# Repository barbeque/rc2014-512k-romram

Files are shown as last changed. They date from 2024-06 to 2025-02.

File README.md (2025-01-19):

## The Board
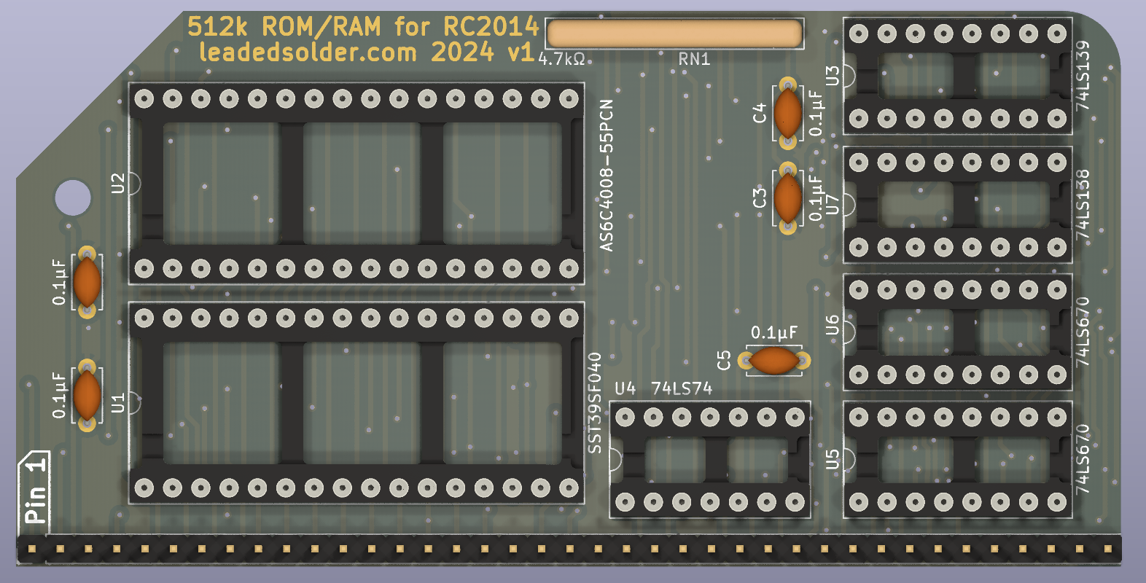
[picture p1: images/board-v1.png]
The board of version 1


## Licensing and Credits
This board is based on [the schematic listed on the RC2014 website](https://rc2014.co.uk/modules/512k-rom-512k-ram-module/), which is in turn derived from [Sergey Kiselev's Zeta 2 SBC](https://github.com/skiselev/zeta_sbc) (GPLv3). Please honour the licensing for any derivatives made of this board.

Symbol for the AS6C4008 ROM comes from SnapEDA.

## Version 2
Fixed:
 - D0 was not written into the 7474
 - A18 was not connected on the RAM, due to a buggy (copy-paste error) SnapEDA symbol.

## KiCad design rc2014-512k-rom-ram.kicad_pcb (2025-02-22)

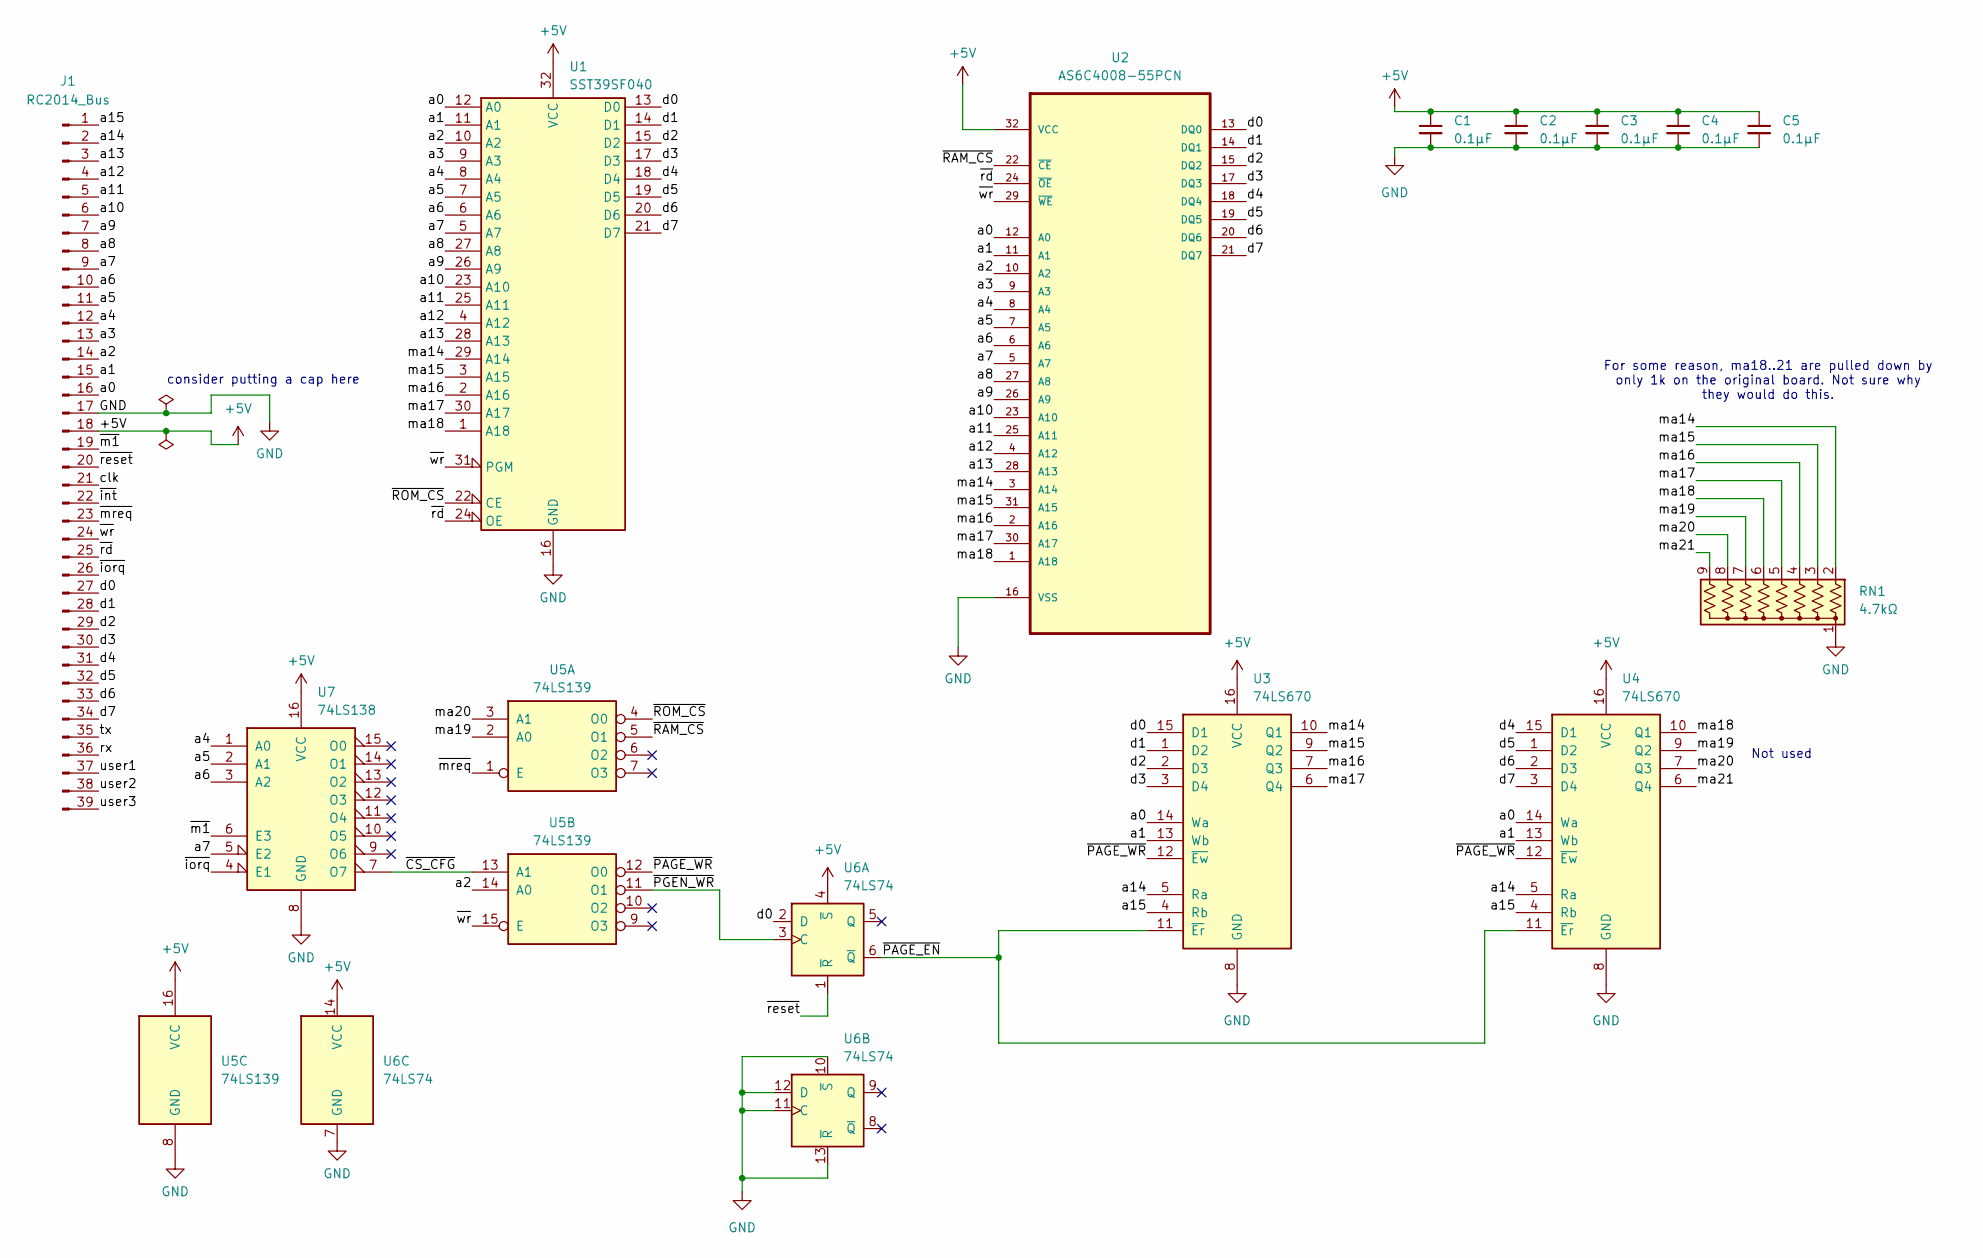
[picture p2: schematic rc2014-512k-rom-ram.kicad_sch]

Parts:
C1, C2, C3, C4, C5: 0.1µF; C_Disc_D4.7mm_W2.5mm_P5.00mm
J1: RC2014_Bus; PinHeader_1x39_P2.54mm_Vertical
RN1: 4.7kΩ; R_Array_SIP9
U1: SST39SF040; DIP-32_W15.24mm_Socket_LongPads
U2: AS6C4008-55PCN; DIP254P1524X393-32; MPN AS6C4008-55PCN
U3, U4: 74LS670; DIP-16_W7.62mm_Socket_LongPads
U5: 74LS139; DIP-16_W7.62mm_Socket_LongPads
U6: 74LS74; DIP-14_W7.62mm_Socket_LongPads
U7: 74LS138; DIP-16_W7.62mm_Socket_LongPads

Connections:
+5V: C1.1, C2.1, C3.1, C4.1, C5.1, J1.18, U1.32 (VCC), U2.32 (VCC), U3.16 (VCC), U4.16 (VCC), U5.16 (VCC), U6.4 (~S), U6.14 (VCC), U7.16 (VCC)
/a0: J1.16, U1.12 (A0), U2.12 (A0), U3.14 (Wa), U4.14 (Wa)
/a1: J1.15, U1.11 (A1), U2.11 (A1), U3.13 (Wb), U4.13 (Wb)
/a2: J1.14, U1.10 (A2), U2.10 (A2), U5.14 (A0)
/a3: J1.13, U1.9 (A3), U2.9 (A3)
/a4: J1.12, U1.8 (A4), U2.8 (A4), U7.1 (A0)
/a5: J1.11, U1.7 (A5), U2.7 (A5), U7.2 (A1)
/a6: J1.10, U1.6 (A6), U2.6 (A6), U7.3 (A2)
/a7: J1.9, U1.5 (A7), U2.5 (A7), U7.5 (E2)
/a8: J1.8, U1.27 (A8), U2.27 (A8)
/a9: J1.7, U1.26 (A9), U2.26 (A9)
/a10: J1.6, U1.23 (A10), U2.23 (A10)
/a11: J1.5, U1.25 (A11), U2.25 (A11)
/a12: J1.4, U1.4 (A12), U2.4 (A12)
/a13: J1.3, U1.28 (A13), U2.28 (A13)
/a14: J1.2, U3.5 (Ra), U4.5 (Ra)
/a15: J1.1, U3.4 (Rb), U4.4 (Rb)
/clk: J1.21
/d0: J1.27, U1.13 (D0), U2.13 (DQ0), U3.15 (D1), U6.2 (D)
/d1: J1.28, U1.14 (D1), U2.14 (DQ1), U3.1 (D2)
/d2: J1.29, U1.15 (D2), U2.15 (DQ2), U3.2 (D3)
/d3: J1.30, U1.17 (D3), U2.17 (DQ3), U3.3 (D4)
/d4: J1.31, U1.18 (D4), U2.18 (DQ4), U4.15 (D1)
/d5: J1.32, U1.19 (D5), U2.19 (DQ5), U4.1 (D2)
/d6: J1.33, U1.20 (D6), U2.20 (DQ6), U4.2 (D3)
/d7: J1.34, U1.21 (D7), U2.21 (DQ7), U4.3 (D4)
/ma14: RN1.2 (R1), U1.29 (A14), U2.3 (A14), U3.10 (Q1)
/ma15: RN1.3 (R2), U1.3 (A15), U2.31 (A15), U3.9 (Q2)
/ma16: RN1.4 (R3), U1.2 (A16), U2.2 (A16), U3.7 (Q3)
/ma17: RN1.5 (R4), U1.30 (A17), U2.30 (A17), U3.6 (Q4)
/ma18: RN1.6 (R5), U1.1 (A18), U2.1 (A18), U4.10 (Q1)
/ma19: RN1.7 (R6), U4.9 (Q2), U5.2 (A0)
/ma20: RN1.8 (R7), U4.7 (Q3), U5.3 (A1)
/ma21: RN1.9 (R8), U4.6 (Q4)
/rx: J1.36
/tx: J1.35
/user1: J1.37
/user2: J1.38
/user3: J1.39
/~CS_CFG: U5.13 (A1), U7.7 (O7)
/~PAGE_EN: U3.11 (~Er), U4.11 (~Er), U6.6 (~Q)
/~PAGE_WR: U3.12 (~Ew), U4.12 (~Ew), U5.12 (O0)
/~PGEN_WR: U5.11 (O1), U6.3 (C)
/~RAM_CS: U2.22 (CE), U5.5 (O1)
/~ROM_CS: U1.22 (CE), U5.4 (O0)
/~int: J1.22
/~iorq: J1.26, U7.4 (E1)
/~m1: J1.19, U7.6 (E3)
/~mreq: J1.23, U5.1 (E)
/~rd: J1.25, U1.24 (OE), U2.24 (OE)
/~reset: J1.20, U6.1 (~R)
/~wr: J1.24, U1.31 (PGM), U2.29 (WE), U5.15 (E)
GND: C1.2, C2.2, C3.2, C4.2, C5.2, J1.17, RN1.1 (common), U1.16 (GND), U2.16 (VSS), U3.8 (GND), U4.8 (GND), U5.8 (GND), U6.7 (GND), U6.10 (~S), U6.11 (C), U6.12 (D), U6.13 (~R), U7.8 (GND)

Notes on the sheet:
Not used
For some reason, ma18..21 are pulled down by only 1k on the original board. Not sure why they would do this.
consider putting a cap here

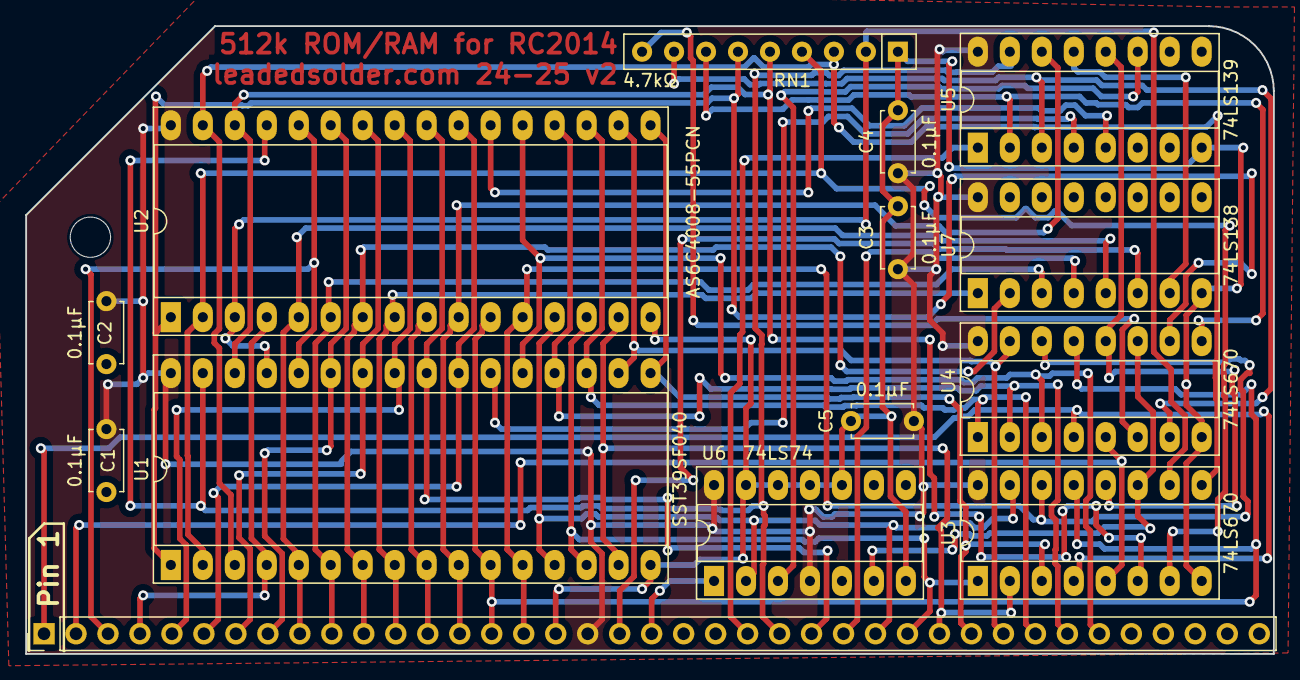
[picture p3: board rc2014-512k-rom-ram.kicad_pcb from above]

Board: 2 copper layers, 99.1 x 49.9 mm, 14 parts (0 on the bottom side), 46 nets.

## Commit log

2024-06-25 Redrawn schematic
    [rc2014-512k-rom-ram.kicad_pcb, rc2014-512k-rom-ram.kicad_sch]
2024-06-25 Finally fully routed
    [rc2014-512k-rom-ram.kicad_pcb, rc2014-512k-rom-ram.kicad_sch]
2024-06-25 Send v1 to fab
    [rc2014-512k-rom-ram.kicad_pcb]
2024-06-25 Send to JLCPCB
    [rc2014-512k-rom-ram.kicad_pcb]
2024-06-25 OSHW logo
    [rc2014-512k-rom-ram.kicad_pcb]
2025-01-18 Fix missing d0 line
    [rc2014-512k-rom-ram.kicad_pcb, rc2014-512k-rom-ram.kicad_sch]
2025-01-18 A18 shouldn't be broken on 4008
    [rc2014-512k-rom-ram.kicad_pcb, rc2014-512k-rom-ram.kicad_sch]
2025-01-19 Fix root symbol
    [rc2014-512k-rom-ram.kicad_sch]
2025-01-20 Fix power flag complaint
    [rc2014-512k-rom-ram.kicad_sch]
2025-01-20 Schematic cleanup
    [rc2014-512k-rom-ram.kicad_sch]
2025-02-22 Solid fill
    [rc2014-512k-rom-ram.kicad_pcb]
2025-02-22 KiCad 9; fix designators
    [rc2014-512k-rom-ram.kicad_pcb, rc2014-512k-rom-ram.kicad_sch]
2026-06-20 Comments on memory map
    [rc2014-512k-rom-ram.kicad_sch]
2026-06-20 Big gate oops
    [rc2014-512k-rom-ram.kicad_sch]
